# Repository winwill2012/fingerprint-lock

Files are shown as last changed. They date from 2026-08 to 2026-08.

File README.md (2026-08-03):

# 智能保险柜

基于 **ESP32-C3**、**海凌科 ZW101** 指纹模块与 **Android 原生 App** 的智能开锁方案：本地指纹识别开锁，手机端远程开锁与指纹管理，支持 BLE 配网与 MQTT 通信。

| 端 | 目录 | 技术栈 |
| --- | --- | --- |
| 固件 | `firmware/` | PlatformIO · ESP32-C3 · Arduino |
| App | `android/` | Android Studio · Kotlin · MQTT（TCP 1883） |

App 名称：**智能保险柜**（包名 `com.fingerprintlock.app`，最低 Android 8.0 / API 26）。

---

## 功能概览

**设备端**

- 指纹 1:N 识别成功后开锁（电磁锁脉冲，硬限制 ≤500ms）
- 最多 50 枚指纹模板；录入 / 删除 / 清空 / 备注
- BLE 配网（设备名 `FPLock-XXXX`），WiFi 凭据写入 NVS
- MQTT 上报状态、电量、开锁事件；接收远程指令
- 可选待机呼吸灯；识别成功 / 失败、录入过程仍有灯效提示

**手机端**

- 首页：设备在线状态、电量、远程开锁、最近事件
- 指纹：列表管理、录入引导、改备注、删除、清空
- 设置：MQTT 参数、呼吸灯开关、BLE 配网

---

## 仓库结构

```
fingerprint-lock/
├── firmware/          # 门锁固件（PlatformIO）
│   ├── include/       # config.h 引脚 / MQTT / 安全参数
│   ├── src/           # main.cpp、ble_prov 等
│   └── platformio.ini
├── android/           # Android Studio 工程（请打开此目录）
│   ├── app/
│   └── asserts/       # 设计资源（Logo、Tab 图标等）
└── README.md
```

---

## 硬件连接

| 功能 | 引脚 | 说明 |
| --- | --- | --- |
| 指纹 TX → ESP RX | IO4 | ZW101，57600 baud |
| 指纹 RX ← ESP TX | IO5 | |
| 电子锁 | IO0 | **高电平开锁**，须经三极管 / MOS / 继电器驱动，禁止直驱 |
| 电池采样 | IO3 | 分压后 ADC（默认按 16340：3.0V～4.2V） |

其他约定：

- 开锁脉冲默认 **300ms**（编译期禁止超过 500ms）
- 固件版本见 `firmware/include/config.h` 中 `FW_VERSION`

---

## 固件（`firmware/`）

### 编译与烧录

```bash
cd firmware
# 按需编辑 include/config.h（MQTT 默认已填；WiFi 由 App BLE 配网）
pio run -t upload
pio device monitor   # 可选：查看日志
```

### 主要能力

- MQTT JSON 指令：`unlock` / `enroll` / `cancel` / `delete` / `rename` / `clear` / `list` / `status` / `led`
- 指纹注册表保存在 NVS（备注、时间戳）；列表以注册表为准，避免 UART 偶发读失败导致列表乱跳
- 删除 / 清空会校验模块 Flash，避免「App 列表空了还能开锁」
- BLE 与 WiFi 共存时使用 `WIFI_PS_MIN_MODEM`，避免 ESP32-C3 异常复位

---

## Android App（`android/`）

### 打开工程

1. 安装 [Android Studio](https://developer.android.com/studio)（建议较新稳定版）
2. **File → Open** → 选择本仓库的 **`android/`** 目录（不要打开仓库根目录）
3. 等待 Gradle Sync
4. 连接真机运行（BLE 配网需要真机蓝牙）

### 页面说明

| 页面 | 功能 |
| --- | --- |
| 首页 | 在线状态、电量、远程开锁按钮、最近开锁 / 事件 |
| 指纹 | 录入、备注、删除、清空；列表与设备注册表同步 |
| 设置 | MQTT Host/Port/账号/Topic、呼吸灯、进入 BLE 配网 |

### 配网流程

1. 烧录固件，设备广播 `FPLock-XXXX`
2. App → 设置 → **BLE 配网** → 授予蓝牙 / 定位（及 Android 12+「附近的设备」）权限
3. 扫描并连接设备 → 选择 **2.4GHz WiFi**、输入密码 → 下发
4. 配网成功后，App 通过 MQTT 与设备通信即可远程开锁、管理指纹

### 默认 MQTT（可在设置中修改）

| 项 | 默认值 |
| --- | --- |
| 协议 | TCP `iot.welinklab.com:1883`（明文 MQTT，非 WSS） |
| 用户 | 见 `config.h` / App 设置页默认值 |
| 指令 Topic | `welink/.../fingerprint-lock-cmd` |
| 上报 Topic | `welink/.../fingerprint-lock-upload` |

> 账号密码写在工程默认配置中，若仓库公开请务必更换。

---

## MQTT 协议摘要

**App → 设备（cmd）** 常见字段：`type`，以及按需的 `id` / `note` / `enable` 等。

| type | 作用 |
| --- | --- |
| `unlock` | 远程开锁 |
| `enroll` | 录入指纹（`id`、`note`） |
| `cancel` | 取消录入 |
| `delete` / `clear` | 删除单枚 / 清空全部 |
| `rename` | 修改备注 |
| `list` / `status` | 拉取列表 / 状态 |
| `led` | 开关待机呼吸灯 |

**设备 → App（upload）**：`status`、`list`、`enroll` 过程相位、`unlock` 事件、`delete`/`clear`/`rename` 回执、`error` 等。

---

## 注意事项

1. **开锁脉冲 ≤500ms**，IO0 必须经驱动电路接锁，否则可能烧毁模块或锁体  
2. 指纹模块与灯控共用 UART，忙时不要依赖全量扫库刷新列表  
3. Android 12+ BLE 扫描需要「附近的设备」与定位等相关权限  
4. 仅支持 2.4GHz WiFi；配网设备名形如 `FPLock-XXXX`  
5. 公开或量产前更换 MQTT 账号、密码，并视需要启用 `MQTT_CMD_KEY`

---

## 许可与声明

本仓库为智能柜 / 门锁类演示与产品原型代码。硬件选型、锁体驱动与安规需按实际产品自行评估与测试。

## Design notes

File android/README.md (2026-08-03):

# 智能保险柜 · Android App

用 **Android Studio** 打开**本目录**（`android/`），不要打开仓库根目录。

## 快速开始

1. Android Studio → Open → 选择本文件夹  
2. Sync Gradle  
3. 连接真机运行（BLE 配网需要真机）

| 项 | 值 |
| --- | --- |
| 应用名 | 智能保险柜 |
| 包名 | `com.fingerprintlock.app` |
| 最低系统 | Android 8.0（API 26） |

完整硬件说明、固件烧录与 MQTT 协议见仓库根目录 [README.md](../README.md)。

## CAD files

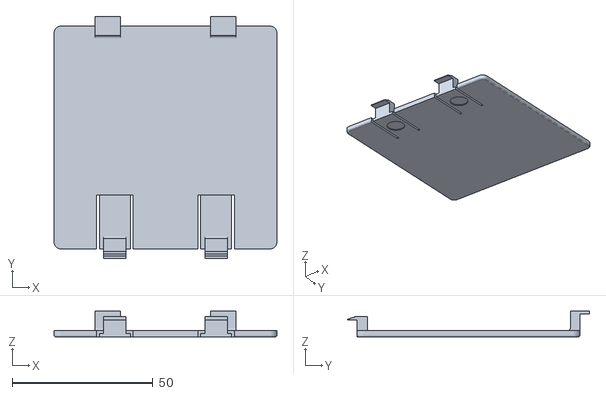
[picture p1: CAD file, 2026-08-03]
相关资源/3D模型/保险箱底部.stl
79.3 x 86.0 x 9.20

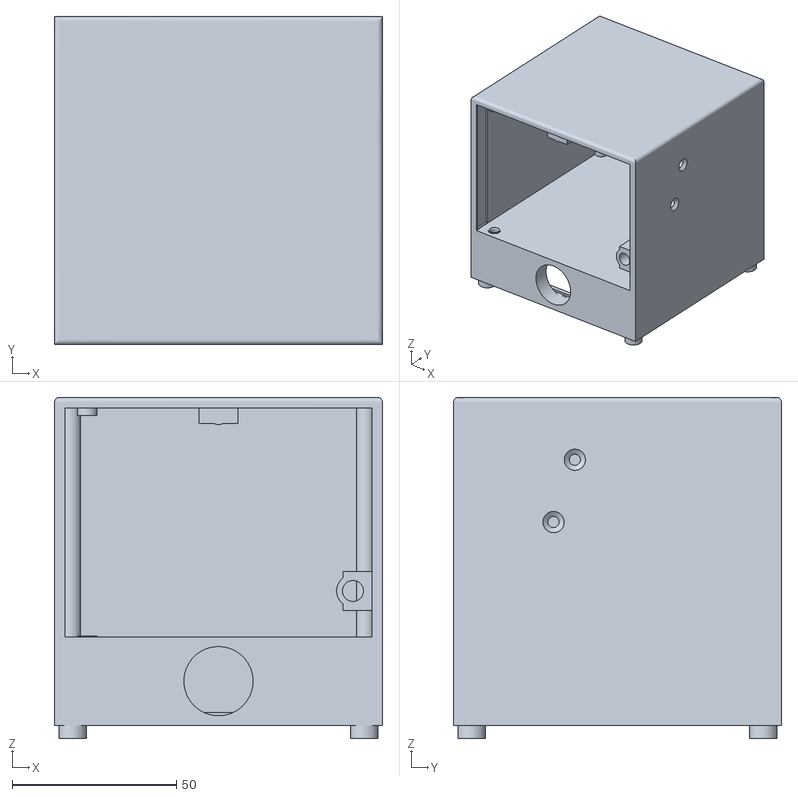
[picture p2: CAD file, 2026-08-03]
相关资源/3D模型/密码箱总成.stl
100.0 x 100.0 x 104.0

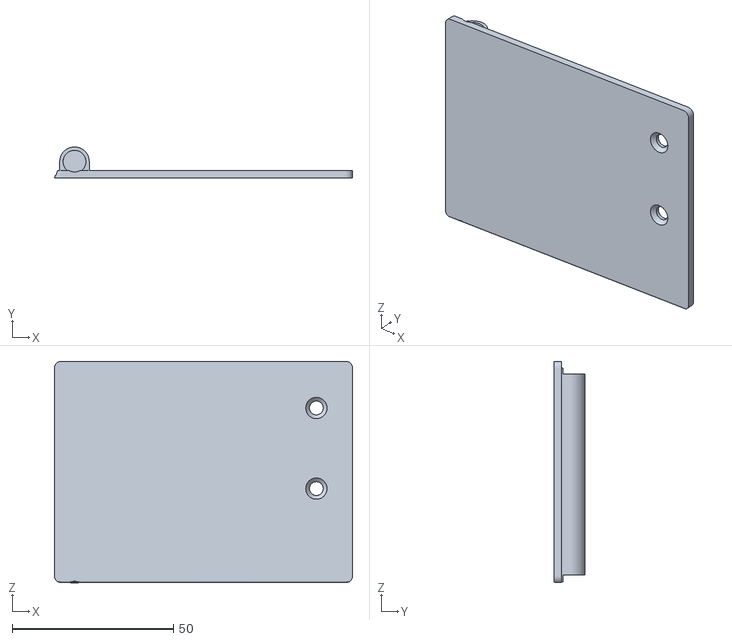
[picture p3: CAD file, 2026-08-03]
相关资源/3D模型/保险箱门.stl
92.4 x 9.70 x 68.6

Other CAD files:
相关资源/3D模型/密码箱工程.f3d

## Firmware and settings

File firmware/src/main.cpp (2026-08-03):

/**
 * ============================================================
 * 智能指纹锁固件 —— ESP32-C3
 * ------------------------------------------------------------
 * 硬件：
 *   - 指纹模块（海凌科 ZW101，兼容 AS608 类 UART 协议，默认 57600）
 *      模块 TX -> IO4 (Serial1 RX)
 *      模块 RX <- IO5 (Serial1 TX)
 *   - 电子锁：IO0 高电平开锁，脉冲宽度 LOCK_PULSE_MS（默认 300ms，≤500ms）
 *   - 电池：IO3 (ADC1_CH3) 经两个 100K 分压采样 16340 电池电压
 * 功能：
 *   - 指纹模块工作在校验模式（1:N 搜索比对），识别成功即开锁
 *   - 手机 App 低功耗蓝牙（BLE）配网，WiFi 凭据存 NVS
 *   - MQTT 远程开锁 / 指纹录入、删除、清空、列表、备注 / 状态与电量上报
 * ============================================================
 */
#include <Arduino.h>
#include <WiFi.h>
#include <PubSubClient.h>
#include <Adafruit_Fingerprint.h>
#include <ArduinoJson.h>
#include <Preferences.h>
#include <vector>
#include <algorithm>
#include <string.h>
#include "config.h"
#include "ble_prov.h"

// ---------------- 硬件对象 ----------------
// Serial1 = UART1，用于指纹模块
Adafruit_Fingerprint finger = Adafruit_Fingerprint(&Serial1);
WiFiClient netClient;
PubSubClient mqtt(netClient);
Preferences prefs;

// ---------------- 开锁状态 ----------------
static bool lockActive = false;        // 开锁脉冲进行中
static unsigned long lockStartMs = 0;  // 脉冲开始时间
static unsigned long lastUnlockAt = 0; // 上次开锁时间（冷却用）

// ---------------- 指纹录入状态机 ----------------
static bool enrollBusy = false;
static volatile bool enrollCancelReq = false;
static int enrollId = -1;
static String enrollNote;
static uint8_t enrollStep = 0;         // 0=等第1次按压 1=等待抬手 2=等第2次按压并合成
static unsigned long enrollDeadline = 0;

// ---------------- 指纹注册表（NVS 保存 id/备注/录入时间） ----------------
struct FpEntry {
  int id;
  String note;
  unsigned long ts;
};
static std::vector<FpEntry> fpRegistry;
static uint32_t fpListSeq = 0;

// ---------------- 其他状态 ----------------
static unsigned long lastBatteryReport = 0;
static unsigned long lastNotFoundPublish = 0;
static unsigned long lastWifiRetry = 0;
static unsigned long lastMqttRetry = 0;
static bool fpReady = false;
static bool ledBreathEnabled = true;  // 仅控制待机呼吸灯；识别/录入提示灯始终保留
static bool fpCmdBusy = false;        // 发灯控时暂停扫描，避免 UART 抢占
static unsigned long lastLedRefreshMs = 0;
static uint8_t lastLedModeRc = 0xFF;
static uint8_t lastLedBlnRc = 0xFF;
static bool ledEffectActive = false;  // 识别/录入提示灯效播放中
static unsigned long ledEffectUntilMs = 0;

void refreshFpCount();
void publishFpList();
void publishEvent(const char *type, const char *phase, int id, int extra, const char *note);
void fpFlushRx();

// ============================================================
//  工具函数
// ============================================================
static unsigned long nowSec() {
  time_t t = time(nullptr);
  return (t > 1600000000) ? (unsigned long)t : (unsigned long)(millis() / 1000);
}

// ============================================================
//  电池
// ============================================================
int readBatteryMv() {
  long sum = 0;
  for (int i = 0; i < BAT_ADC_SAMPLES; i++) {
    sum += analogReadMilliVolts(PIN_BAT);
    delayMicroseconds(300);
  }
  int mv = (int)((sum / BAT_ADC_SAMPLES) * BAT_DIVIDER);
  return constrain(mv, 0, 5000);
}

int batteryPercent(int mv) {
  // 16340 锂电池放电曲线（近似分段线性）
  static const int pts[][2] = {
    {4200, 100}, {4100, 95}, {4000, 88}, {3900, 78}, {3800, 68}, {3700, 57},
    {3600, 46}, {3500, 35}, {3400, 24}, {3300, 15}, {3200, 8}, {3100, 3}, {3000, 0}
  };
  const int n = sizeof(pts) / sizeof(pts[0]);
  if (mv >= pts[0][0]) return 100;
  if (mv <= pts[n - 1][0]) return 0;
  for (int i = 0; i < n - 1; i++) {
    if (mv <= pts[i][0] && mv >= pts[i + 1][0]) {
      float ratio = (float)(pts[i][0] - mv) / (pts[i][0] - pts[i + 1][0]);
      return pts[i][1] - (int)((pts[i][1] - pts[i + 1][1]) * ratio);
    }
  }
  return 50;
}

// ============================================================
//  MQTT 发布
// ============================================================
void publishDoc(DynamicJsonDocument &doc) {
  if (!mqtt.connected()) return;
  char buf[4096];   // 指纹列表 JSON 可能较大
  size_t n = serializeJson(doc, buf, sizeof(buf));
  if (n == 0 || n >= sizeof(buf)) {
    Serial.println("[mqtt] serialize overflow");
    return;
  }
  // 列表等大包偶发失败时重试，避免 App 收到残缺/丢包后条数跳变
  for (int i = 0; i < 3; i++) {
    if (mqtt.publish(MQTT_RESP_TOPIC, (const uint8_t *)buf, n, false)) return;
    delay(20);
  }
  Serial.printf("[mqtt] publish fail len=%u\n", (unsigned)n);
}

void publishEvent(const char *type, const char *phase, int id, int extra, const char *note) {
  DynamicJsonDocument doc(512);
  doc["type"] = type;
  if (phase) doc["phase"] = phase;
  if (id >= 0) doc["id"] = id;
  if (extra >= 0) doc["extra"] = extra;
  if (note && strlen(note)) doc["note"] = note;
  publishDoc(doc);
}

void publishError(const char *code) {
  publishEvent("error", code, -1, -1, nullptr);
}

void publishStatus(bool force) {
  (void)force;
  int mv = readBatteryMv();
  DynamicJsonDocument doc(768);
  doc["type"] = "status";
  doc["online"] = true;
  doc["battery_mv"] = mv;
  doc["battery_pct"] = batteryPercent(mv);
  doc["fp_count"] = (int)fpRegistry.size();  // 以注册表为准，不用模块 templateCount（会抖动）
  doc["fp_reg"] = (int)fpRegistry.size();
  if (fpReady) {
    // 仅作参考，不驱动 App 列表
    doc["fp_tpl"] = finger.templateCount;
  }
  doc["ip"] = WiFi.localIP().toString();
  doc["rssi"] = WiFi.RSSI();
  doc["uptime"] = (int)(millis() / 1000);
  doc["enroll_busy"] = enrollBusy;
  doc["led_breath"] = ledBreathEnabled;
  doc["fw"] = FW_VERSION;
  publishDoc(doc);
}

void publishUnlock(const char *source, int fpId, int confidence) {
  int mv = readBatteryMv();
  DynamicJsonDocument doc(512);
  doc["type"] = "unlock";
  doc["source"] = source;
  doc["fp_id"] = fpId;
  doc["confidence"] = confidence;
  doc["battery_mv"] = mv;
  doc["battery_pct"] = batteryPercent(mv);
  doc["ts"] = (long)nowSec();
  publishDoc(doc);
}

// ============================================================
//  开锁控制（脉冲 ≤ LOCK_PULSE_MS，非阻塞）
// ============================================================
void requestUnlock(const char *source, int fpId, int confidence) {
  unsigned long now = millis();
  if (lockActive) return;                                  // 已有脉冲进行中
  if (now - lastUnlockAt < UNLOCK_COOLDOWN_MS) return;     // 冷却防连发
  lastUnlockAt = now;
  lockStartMs = now;
  lockActive = true;
  digitalWrite(PIN_LOCK, HIGH);                            // 开锁
  publishUnlock(source, fpId, confidence);
}

void tickLock() {
  if (lockActive && (millis() - lockStartMs >= LOCK_PULSE_MS)) {
    digitalWrite(PIN_LOCK, LOW);                           // 关锁
    lockActive = false;
    Serial.printf("[lock] 脉冲结束，通电 %.0f ms\n", (double)(millis() - lockStartMs));
  }
}

// ============================================================
//  指纹注册表（NVS）
// ============================================================
void fpLoadRegistry() {
  fpRegistry.clear();
  prefs.begin("fp", false);
  String s = prefs.getString("meta", "");
  if (!s.isEmpty()) {
    DynamicJsonDocument doc(4096);
    if (!deserializeJson(doc, s)) {
      JsonArray arr = doc.as<JsonArray>();
      for (JsonObject o : arr) {
        FpEntry e;
        e.id = o["id"] | -1;
        e.note = (const char *)(o["note"] | "");
        e.ts = o["ts"] | 0UL;
        if (e.id >= 0) fpRegistry.push_back(e);
      }
    }
  }
  prefs.end();
  Serial.printf("[fp] 注册表已加载，共 %d 条\n", (int)fpRegistry.size());
}

void fpSaveRegistry() {
  DynamicJsonDocument doc(4096);
  JsonArray arr = doc.to<JsonArray>();
  for (auto &e : fpRegistry) {
    JsonObject o = arr.createNestedObject();
    o["id"] = e.id;
    o["note"] = e.note;
    o["ts"] = e.ts;
  }
  String out;
  serializeJson(doc, out);
  prefs.begin("fp", false);
  prefs.putString("meta", out);
  prefs.end();
}

void fpAddEntry(int id, const String &note) {
  for (auto &e : fpRegistry) {
    if (e.id == id) { e.note = note; e.ts = nowSec(); fpSaveRegistry(); return; }
  }
  FpEntry e;
  e.id = id; e.note = note; e.ts = nowSec();
  fpRegistry.push_back(e);
  fpSaveRegistry();
}

bool fpRenameEntry(int id, const String &note) {
  for (auto &e : fpRegistry) {
    if (e.id == id) { e.note = note; fpSaveRegistry(); return true; }
  }
  return false;
}

void fpRemoveEntry(int id) {
  for (size_t i = 0; i < fpRegistry.size(); i++) {
    if (fpRegistry[i].id == id) {
      fpRegistry.erase(fpRegistry.begin() + i);
      fpSaveRegistry();
      return;
    }
  }
}

void fpClearRegistry() {
  fpRegistry.clear();
  fpSaveRegistry();
}

bool fpIdInRegistry(int id) {
  for (auto &e : fpRegistry) {
    if (e.id == id) return true;
  }
  return false;
}

/** 槽位是否占用。UART 通信失败时按占用处理，避免误覆盖已有模板。 */
bool fpSlotTaken(int id) {
  if (fpIdInRegistry(id)) return true;
  if (!fpReady) return false;
  uint8_t r = finger.loadModel(id);
  if (r == FINGERPRINT_OK) return true;
  if (r == FINGERPRINT_PACKETRECIEVEERR || r == FINGERPRINT_TIMEOUT ||
      r == FINGERPRINT_BADPACKET) {
    return true;
  }
  return false;
}

int fpFindFreeId() {
  for (int i = 0; i < FP_MAX_TEMPLATES; i++) {
    if (!fpSlotTaken(i)) return i;
  }
  return -1;
}

/** 确认槽位已空。通信失败视为未确认（不能当已删除）。 */
bool fpSlotVerifiedEmpty(int id) {
  if (!fpReady) return false;
  uint8_t r = finger.loadModel(id);
  if (r == FINGERPRINT_OK) return false;
  if (r == FINGERPRINT_PACKETRECIEVEERR || r == FINGERPRINT_TIMEOUT ||
      r == FINGERPRINT_BADPACKET) {
    return false;
  }
  return true;
}

/** 删除单个模板。deleteModel 成功即视为成功；校验仅作加强，失败不否决。 */
bool fpDeleteTemplate(int id) {
  if (!fpReady) return false;
  for (int attempt = 0; attempt < 3; attempt++) {
    fpFlushRx();
    uint8_t r = finger.deleteModel((uint16_t)id);
    delay(50);
    if (r == FINGERPRINT_OK) return true;
    // 槽位本就为空
    if (fpSlotVerifiedEmpty(id)) return true;
    delay(30);
  }
  // 最后再确认一次：已空也算删除成功
  return fpSlotVerifiedEmpty(id);
}

/** 清空模块全部模板：emptyDatabase + 扫残留逐个删，最后校验。 */
bool fpWipeModule() {
  if (!fpReady) return false;

  uint8_t r = finger.emptyDatabase();
  Serial.printf("[fp] emptyDatabase -> 0x%02X\n", r);
  delay(150);

  // 再扫一遍，清掉 empty 未删净的残留（含注册表外的孤儿模板）
  int left = 0;
  for (int id = 0; id < FP_MAX_TEMPLATES; id++) {
    uint8_t lr = finger.loadModel(id);
    if (lr == FINGERPRINT_OK) {
      if (!fpDeleteTemplate(id)) left++;
    }
  }

  refreshFpCount();
  if (finger.templateCount > 0) {
    Serial.printf("[fp] wipe: templateCount still %d\n", finger.templateCount);
    // templateCount 偶发不准，以 loadModel 为准再扫一次
    left = 0;
    for (int id = 0; id < FP_MAX_TEMPLATES; id++) {
      if (finger.loadModel(id) == FINGERPRINT_OK) left++;
    }
  }

  Serial.printf("[fp] wipe done, residual=%d tpl=%d\n", left, finger.templateCount);
  return left == 0;
}

void refreshFpCount() {
  if (fpReady) finger.getTemplateCount();
}

/** 从模块补齐注册表：只增加确认存在的槽位，绝不因读失败删掉已有项。
 *  全量重建会在 UART 偶发失败时造成列表时而缺 0、时而缺 1。 */
void fpSyncFromModule() {
  if (!fpReady) return;
  if (fpCmdBusy || enrollBusy) {
    Serial.println("[fp] sync skip: uart busy");
    return;
  }

  int added = 0;
  int seen = 0;
  int failLoads = 0;
  bool dirty = false;

  for (int id = 0; id < FP_MAX_TEMPLATES; id++) {
    if (fpCmdBusy || enrollBusy) {
      Serial.println("[fp] sync abort mid-way: uart busy");
      break;
    }
    uint8_t r = finger.loadModel(id);
    if (r == FINGERPRINT_OK) {
      seen++;
      bool exists = false;
      for (auto &e : fpRegistry) {
        if (e.id == id) { exists = true; break; }
      }
      if (!exists) {
        FpEntry e;
        e.id = id;
        e.note = "指纹#" + String(id);
        e.ts = nowSec();
        fpRegistry.push_back(e);
        added++;
        dirty = true;
      }
    } else if (r == FINGERPRINT_PACKETRECIEVEERR || r == FINGERPRINT_TIMEOUT ||
               r == FINGERPRINT_BADPACKET) {
      failLoads++;
    }
    // 其它返回值视为「空槽或不确定」，保留注册表原样，绝不删除
  }

  if (dirty) fpSaveRegistry();
  refreshFpCount();
  Serial.printf("[fp] sync merge seen=%d added=%d fail=%d stored=%d\n",
                seen, added, failLoads, (int)fpRegistry.size());
}

void publishFpList() {
  // 按 id 排序，避免 App 显示顺序跳动
  std::sort(fpRegistry.begin(), fpRegistry.end(),
            [](const FpEntry &a, const FpEntry &b) { return a.id < b.id; });

  fpListSeq++;
  DynamicJsonDocument doc2(4096);
  doc2["type"] = "list";
  doc2["seq"] = fpListSeq;
  doc2["count"] = (int)fpRegistry.size();
  JsonArray arr = doc2.createNestedArray("items");
  for (auto &e : fpRegistry) {
    JsonObject o = arr.createNestedObject();
    o["id"] = e.id;
    o["note"] = e.note;
    o["ts"] = e.ts;
  }
  publishDoc(doc2);
}

// ============================================================
//  指纹模块初始化（带重试，模块上电需要时间）
// ============================================================
bool initFingerprint() {
  for (int i = 0; i < 10; i++) {
    if (finger.verifyPassword()) {
      finger.getTemplateCount();
      Serial.printf("[fp] 指纹模块就绪，已存模板 %d\n", finger.templateCount);
      return true;
    }
    delay(500);
  }
  return false;
}

// ============================================================
//  指纹指示灯（海凌科：PS_BlnAmSw=0x60 / PS_ControlBLN=0x3C）
//  - 开启呼吸：自动模式（待机蓝灯呼吸 + 模块自带识别/录入灯效）
//  - 关闭呼吸：手动模式待机熄灭，但识别成功/失败、录入过程仍手动播提示灯
// ============================================================
void fpFlushRx() {
  while (Serial1.available() > 0) {
    (void)Serial1.read();
  }
}

uint8_t fpSendCmd(uint8_t *data, uint8_t n) {
  fpFlushRx();
  Adafruit_Fingerprint_Packet packet(FINGERPRINT_COMMANDPACKET, n, data);
  finger.writeStructuredPacket(packet);
  uint8_t r = finger.getStructuredPacket(&packet, 1500);
  if (r != FINGERPRINT_OK) return r;
  if (packet.type != FINGERPRINT_ACKPACKET) return FINGERPRINT_PACKETRECIEVEERR;
  return packet.data[0];
}

uint8_t fpBlnAmSw(uint8_t mode) {
  uint8_t d[] = {0x60, mode};
  return fpSendCmd(d, sizeof(d));
}

/** 普通三色灯：func 01呼吸/02闪烁/03常开/04常闭；颜色 bit0蓝 bit1绿 bit2红 */
uint8_t fpControlBlnBasic(uint8_t func, uint8_t startColor, uint8_t endColor, uint8_t cycles) {
  uint8_t d[] = {0x3C, func, startColor, endColor, cycles};
  return fpSendCmd(d, sizeof(d));
}

uint8_t fpControlBlnExt(uint8_t func, uint8_t startColor, uint8_t endOrDuty,
                        uint8_t cycles, uint8_t timeTenths) {
  uint8_t d[] = {0x3C, func, startColor, endOrDuty, cycles, timeTenths};
  return fpSendCmd(d, sizeof(d));
}

void ledLoadPref() {
  prefs.begin("cfg", true);
  ledBreathEnabled = prefs.getBool("led_breath", true);
  prefs.end();
}

void ledSavePref() {
  prefs.begin("cfg", false);
  prefs.putBool("led_breath", ledBreathEnabled);
  prefs.end();
}

/** 恢复待机灯效：开=立即蓝灯呼吸；关=待机熄灭（识别提示灯另播） */
bool applyLedIdle() {
  if (!fpReady) return false;
  fpCmdBusy = true;
  delay(15);
  fpFlushRx();

  // 统一手动模式，便于立即生效（自动模式切呼吸通常要等业务结束/上电）
  lastLedModeRc = fpBlnAmSw(0x00);
  delay(30);
  fpFlushRx();

  if (ledBreathEnabled) {
    // 立刻开启蓝灯呼吸（无限循环）
    lastLedBlnRc = fpControlBlnBasic(0x01, 0x01, 0x01, 0x00);
    delay(30);
    fpFlushRx();
    uint8_t r2 = fpControlBlnExt(0x01, 0x01, 0x01, 0x00, 18);
    if (lastLedBlnRc != FINGERPRINT_OK && r2 == FINGERPRINT_OK) lastLedBlnRc = r2;
  } else {
    lastLedBlnRc = fpControlBlnBasic(0x04, 0x00, 0x00, 0x00);
  }

  ledEffectActive = false;
  lastLedRefreshMs = millis();
  fpCmdBusy = false;
  Serial.printf("[led] idle breath=%d BlnAmSw=0x%02X ControlBLN=0x%02X\n",
                ledBreathEnabled, lastLedModeRc, lastLedBlnRc);
  return lastLedModeRc == FINGERPRINT_OK || lastLedBlnRc == FINGERPRINT_OK;
}

bool applyLedBreath() { return applyLedIdle(); }

void setLedBreath(bool on) {
  ledBreathEnabled = on;
  ledSavePref();
  bool ok = false;
  for (int i = 0; i < 2 && !ok; i++) {
    ok = applyLedIdle();
    if (!ok) delay(40);
  }
  char note[24];
  snprintf(note, sizeof(note), "%s m%02Xb%02X", ok ? "ok" : "fail",
           lastLedModeRc, lastLedBlnRc);
  publishEvent("led", on ? "on" : "off", -1, -1, note);
}

/** 识别/录入提示灯：无论是否开启待机呼吸，都手动播放，结束后恢复待机 */
static void ledBeginEffect(unsigned long durationMs) {
  ledEffectActive = true;
  ledEffectUntilMs = millis() + durationMs;
  lastLedRefreshMs = millis();
}

void ledPlaySuccess() {
  if (!fpReady) return;
  fpCmdBusy = true;
  delay(10);
  fpFlushRx();
  fpControlBlnBasic(0x03, 0x02, 0x02, 0); // 绿灯常亮片刻
  fpCmdBusy = false;
  ledBeginEffect(900);
}

void ledPlayFail() {
  if (!fpReady) return;
  fpCmdBusy = true;
  delay(10);
  fpFlushRx();
  fpControlBlnBasic(0x02, 0x04, 0x04, 3); // 红灯闪 3 次
  fpCmdBusy = false;
  ledBeginEffect(1200);
}

void ledPlayWaitFinger() {
  if (!fpReady) return;
  fpCmdBusy = true;
  delay(10);
  fpFlushRx();
  fpControlBlnExt(0x02, 0x01, 0x18, 0x00, 10); // 蓝灯慢闪提示放手指
  fpCmdBusy = false;
  ledBeginEffect(20000);
}

void ledMaintain() {
  if (!fpReady || fpCmdBusy || enrollBusy) return;

  if (ledEffectActive) {
    if ((long)(millis() - ledEffectUntilMs) >= 0) {
      ledEffectActive = false;
      if (!enrollBusy) applyLedIdle();
    }
    return;
  }

  // 呼吸灯开启后不要周期性重发 ControlBLN，否则会打断识别/删除 UART
  // 仅在关闭待机灯时偶尔确认熄灭
  if (ledBreathEnabled) return;

  if (millis() - lastLedRefreshMs < 15000UL) return;
  applyLedIdle();
}

// ============================================================
//  指纹录入状态机（由主循环驱动）
// ============================================================
void enrollTick() {
  if (!enrollBusy) return;
  if (enrollCancelReq) {
    enrollCancelReq = false;
    enrollBusy = false;
    publishEvent("enroll", "canceled", enrollId, -1, nullptr);
    applyLedIdle();
    return;
  }

  if (millis() > enrollDeadline) {
    enrollBusy = false;
    publishEvent("enroll", "failed", enrollId, -1, "timeout");
    ledPlayFail();
    return;
  }

  if (enrollStep == 0) {                    // 等待第 1 次按压
    uint8_t r = finger.getImage();
    if (enrollCancelReq || !enrollBusy) { enrollCancelReq = false; return; }
    if (r == FINGERPRINT_OK) {
      r = finger.image2Tz(1);
      if (r == FINGERPRINT_OK) {
        enrollStep = 1;
        enrollDeadline = millis() + ENROLL_TIMEOUT_MS;
        publishEvent("enroll", "finger1_ok", enrollId, -1, nullptr);
        publishEvent("enroll", "lift_finger", enrollId, -1, nullptr);
        ledPlaySuccess(); // 短绿提示第 1 次成功（关闭呼吸时）
      } else {
        enrollBusy = false;
        publishEvent("enroll", "failed", enrollId, r, "image_fail");
        ledPlayFail();
      }
    }
  } else if (enrollStep == 1) {             // 等待抬手（避免两次采到同一根手指）
    uint8_t r = finger.getImage();
    if (enrollCancelReq || !enrollBusy) { enrollCancelReq = false; return; }
    if (r == FINGERPRINT_NOFINGER) {
      enrollStep = 2;
      enrollDeadline = millis() + ENROLL_TIMEOUT_MS;
      publishEvent("enroll", "wait_finger2", enrollId, -1, nullptr);
      ledPlayWaitFinger();
    }
  } else {                                  // 等待第 2 次按压并合成存储
    uint8_t r = finger.getImage();
    if (enrollCancelReq || !enrollBusy) { enrollCancelReq = false; return; }
    if (r == FINGERPRINT_OK) {
      r = finger.image2Tz(2);
      if (r != FINGERPRINT_OK) {
        enrollBusy = false;
        publishEvent("enroll", "failed", enrollId, r, "image_fail");
        ledPlayFail();
        return;
      }
      r = finger.createModel();
      if (r == FINGERPRINT_ENROLLMISMATCH) {
        enrollBusy = false;
        publishEvent("enroll", "failed", enrollId, -1, "mismatch");
        ledPlayFail();
        return;
      }
      if (r != FINGERPRINT_OK) {
        enrollBusy = false;
        publishEvent("enroll", "failed", enrollId, r, "model_fail");
        ledPlayFail();
        return;
      }
      r = finger.storeModel(enrollId);
      if (r != FINGERPRINT_OK) {
        enrollBusy = false;
        publishEvent("enroll", "failed", enrollId, r, "store_fail");
        ledPlayFail();
        return;
      }
      fpAddEntry(enrollId, enrollNote);
      refreshFpCount();
      publishEvent("enroll", "done", enrollId, -1, enrollNote.c_str());
      // 立刻推列表，避免 App 再拉 list 触发全量 sync 把刚写入的槽位「扫丢」
      publishFpList();
      enrollBusy = false;
      ledPlaySuccess();
    }
  }
}

// ============================================================
//  指纹扫描（校验模式：1:N 搜索比对）
// ============================================================
void scanFingerprint() {
  if (fpCmdBusy || enrollBusy) return;
  static unsigned long lastScan = 0;
  unsigned long now = millis();
  if (now - lastScan < 120) return;         // 轮询节流
  lastScan = now;

  // 灯控后清一下总线，避免残留应答干扰采图
  fpFlushRx();
  uint8_t r = finger.getImage();
  if (r != FINGERPRINT_OK) return;          // 无手指 / 采集失败，忽略
  r = finger.image2Tz();
  if (r != FINGERPRINT_OK) return;

  r = finger.fingerFastSearch();
  if (r == FINGERPRINT_OK) {
    // 识别成功 -> 开锁
    requestUnlock("finger", finger.fingerID, finger.confidence);
    ledPlaySuccess();
  } else if (r == FINGERPRINT_NOTFOUND) {
    // 指纹存在但未匹配，节流上报
    if (now - lastNotFoundPublish > 5000) {
      lastNotFoundPublish = now;
      DynamicJsonDocument doc(128);
      doc["type"] = "scan";
      doc["result"] = "not_found";
      publishDoc(doc);
    }
    ledPlayFail();
  }
}

// ============================================================
//  MQTT 指令处理（回调只入队，主循环执行，避免在 callback 里 publish 卡死）
// ============================================================
static char mqttCmdBuf[768];
static volatile unsigned mqttCmdLen = 0;
static volatile bool mqttCmdPending = false;
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
void loop() {
  bleProvLoop();
  handleNetwork();
  drainMqttCommands();
  tickLock();
  ledMaintain();

  // 指纹模块掉线时周期重试
  if (!fpReady) {
    static unsigned long lastFpRetry = 0;
    if (millis() - lastFpRetry > 10000) {
      lastFpRetry = millis();
      fpReady = initFingerprint();
      if (fpReady) applyLedIdle();
    }
  }

  if (enrollBusy) {
    enrollTick();                 // 录入期间暂停扫描
  } else if (fpReady) {
    scanFingerprint();            // 校验模式：识别成功即开锁
  }

  // 周期状态/电量上报
  if (millis() - lastBatteryReport >= BAT_REPORT_INTERVAL_MS) {
    lastBatteryReport = millis();
    publishStatus(false);
  }
}

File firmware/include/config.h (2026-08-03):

#pragma once
/**
 * ============================================================
 * 指纹锁 ESP32-C3 固件配置
 * WiFi 通过手机 App BLE 配网写入 NVS，此处不再硬编码账号密码
 * ============================================================
 */

// ---------------- MQTT ----------------
// App 端同样使用 TCP：tcp://iot.welinklab.com:1883
#define MQTT_HOST       "iot.welinklab.com"
#define MQTT_PORT       1883
#define MQTT_USERNAME   "wl_wdjbr6wp2tzaq"
#define MQTT_PASSWORD   "VVwFcmYIB8kaE1GX_1mb2qHH4ZLQsE_P"
#define MQTT_CLIENT_ID  "fp-lock-esp32c3"

// 主题：与 App「设置」页默认配置保持一致
#define MQTT_CMD_TOPIC   "welink/wl_wdjbr6wp2tzaq/fingerprint-lock-cmd"
#define MQTT_RESP_TOPIC  "welink/wl_wdjbr6wp2tzaq/fingerprint-lock-upload"

// 可选：命令密钥。不为空时，所有指令必须携带相同的 key 字段，否则拒绝执行
#define MQTT_CMD_KEY    ""

// ---------------- 引脚 ----------------
#define PIN_FP_RX   4     // 指纹模块 TX  -> 本引脚 (IO4, UART1 RX)
#define PIN_FP_TX   5     // 指纹模块 RX  <- 本引脚 (IO5, UART1 TX)
#define PIN_LOCK    0     // 电子锁控制（高电平开锁），必须经三极管/MOS/继电器驱动
#define PIN_BAT     3     // 电池电压采样 ADC（IO3 = ADC1_CH3）

#define FP_BAUD     57600 // 海凌科 ZW101 默认波特率 57600

// ---------------- WiFi / RF ----------------
#define WIFI_CONNECT_TIMEOUT_MS    30000
#define WIFI_RETRY_INTERVAL_MS     8000

// ---------------- 开锁 ----------------
// ★★★ 电子锁通电时间不得超过 500ms，默认 300ms 留出安全余量 ★★★
#define LOCK_PULSE_MS        300
#if LOCK_PULSE_MS > 500
#error "LOCK_PULSE_MS 不能超过 500ms！电子锁会烧毁"
#endif
#define UNLOCK_COOLDOWN_MS   2000   // 两次开锁最小间隔，防止手指停留重复触发/连发

// ---------------- 电池 ----------------
// 16340 锂电池（3.0V ~ 4.2V），两个 100K 电阻分压 = Vbat / 2
#define BAT_DIVIDER          2.0f
#define BAT_FULL_MV          4200
#define BAT_EMPTY_MV         3000
#define BAT_ADC_SAMPLES      32
#define BAT_REPORT_INTERVAL_MS  8000   // 8s 心跳；App 15s 无上报则离线

// ---------------- 指纹库 ----------------
#define FP_MAX_TEMPLATES   50       // ZW101 规格书容量为 50 枚
#define ENROLL_TIMEOUT_MS  15000

#define FW_VERSION "1.4.13"

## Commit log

2026-08-02 feat: ESP32-C3 指纹锁固件 + 微信小程序远程控制
    固件 (firmware/):
    - 指纹模块(海凌科 AS608/R307)校验模式 1:N 比对，识别成功经 IO0 开锁
    - 开锁脉冲 300ms，编译期强制 ≤500ms；非阻塞脉冲 + 2s 冷却防连发
    - MQTT：远程开锁、指纹录入/删除/清空/列表/备注、状态与电池心跳、遗嘱消息
    - IO3 ADC 分压采样 16340 电池电压(2×100K)，32 次采样平均
    - 依赖库内置 lib/（Adafruit_Fingerprint / PubSubClient / ArduinoJson 6.21.5），可离线编译
    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
2026-08-03 Replace WeChat mini program with Android app and harden firmware.
    Ship the Kotlin ????? client (MQTT unlock/fingerprint/BLE), remove miniprogram, and improve ESP32-C3 list/delete/LED stability plus project docs.
    [dialog_app.xml, 保险箱底部.stl, 保险箱门.stl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]
2026-08-03 Improve online presence, MQTT reliability, and drop WiFi TX power limit.
    App uses heartbeat/LWT for device online; firmware queues MQTT commands, stops periodic breath LED UART spam, and logs over USB CDC.
